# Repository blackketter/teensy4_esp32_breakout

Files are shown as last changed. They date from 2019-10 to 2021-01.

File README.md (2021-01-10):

A companion sidecar board with an ESP32 module to mate with the [Teensy 4 Header Breakout Board](https://github.com/blackketter/teensy4_header_breakout).  

It's designed to solder to the bottom 8 pins on the right side of the Teensy 4 Header Breakout. 

By default it can be powered by the 3.3v power supply on the Teensy, but this may be insufficient for WiFi transmission.  In that case, populate the power supply parts (C4, C5, U2), cut the 3.3v jumper and provide 5v to the indicated pin.

There's an LED on ESP32 pin IO22.

Designed in KiCad.

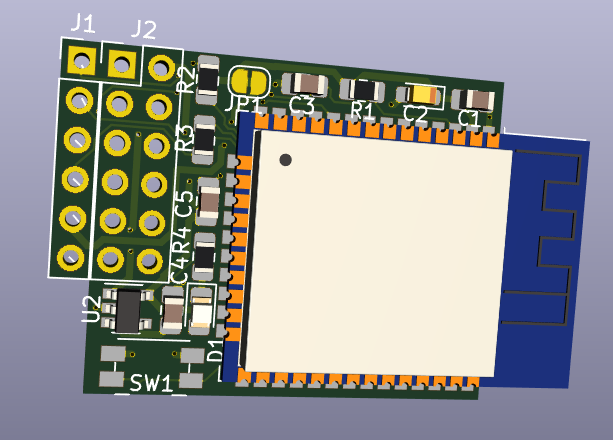
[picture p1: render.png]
breakout render

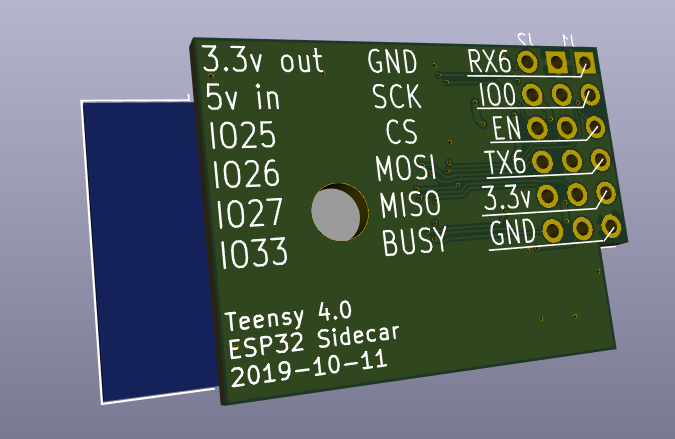
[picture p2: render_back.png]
breakout render back

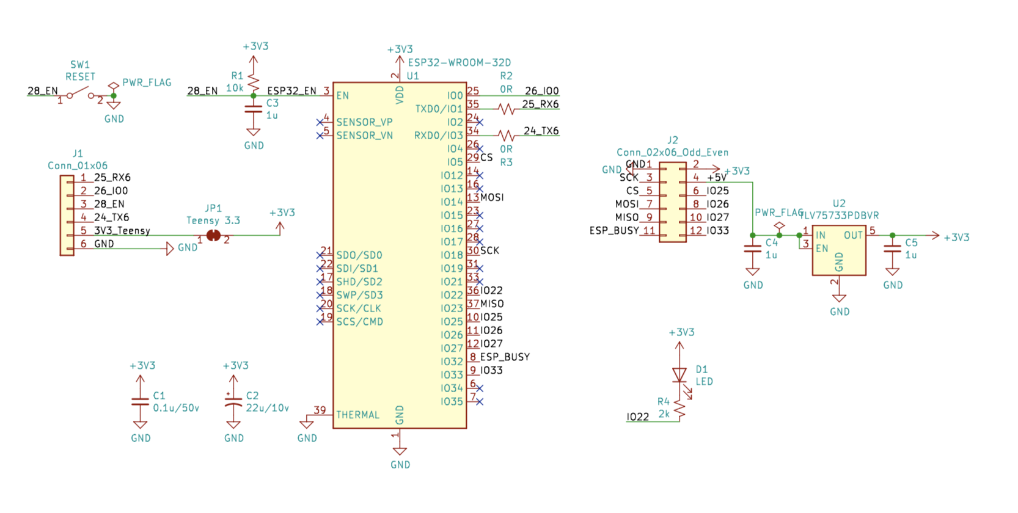
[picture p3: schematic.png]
schematic


Notes:

- In progress: First version worked, this version in progress.
- With longer header pins you should be able to flip the board to be under or over the Teensy 4.0
- Latest revision connects Teensy pin 28 to ESP32 EN

Pinout:

Column 1:

1. Teensy D25/RX6, ESP32 TX0/IO1
2. Teensy D26, ESP32 IO0
3. Teensy D28, ESP32 EN (Reset), On/Off
4. Teensy D24/TX6, ESP32 RX0/IO2
5. Teensy 3.3v
6. GND

Column 2:

1. GND
2. ESP32 IO18/SCK
3. ESP32 IO5/CS
4. ESP32 IO14/MOSI
5. ESP32 IO23/MISO
6. ESP32 IO32/ESP_BUSY

Column 3:

1. 3.3v Regulated Output (if using onboard regulator)
2. 5v Input To Regulator
3. ESP32 IO25, Green LED out
4. ESP32 IO26, Red LED out
5. ESP32 IO27, Blue LED out
6. ESP32 IO33

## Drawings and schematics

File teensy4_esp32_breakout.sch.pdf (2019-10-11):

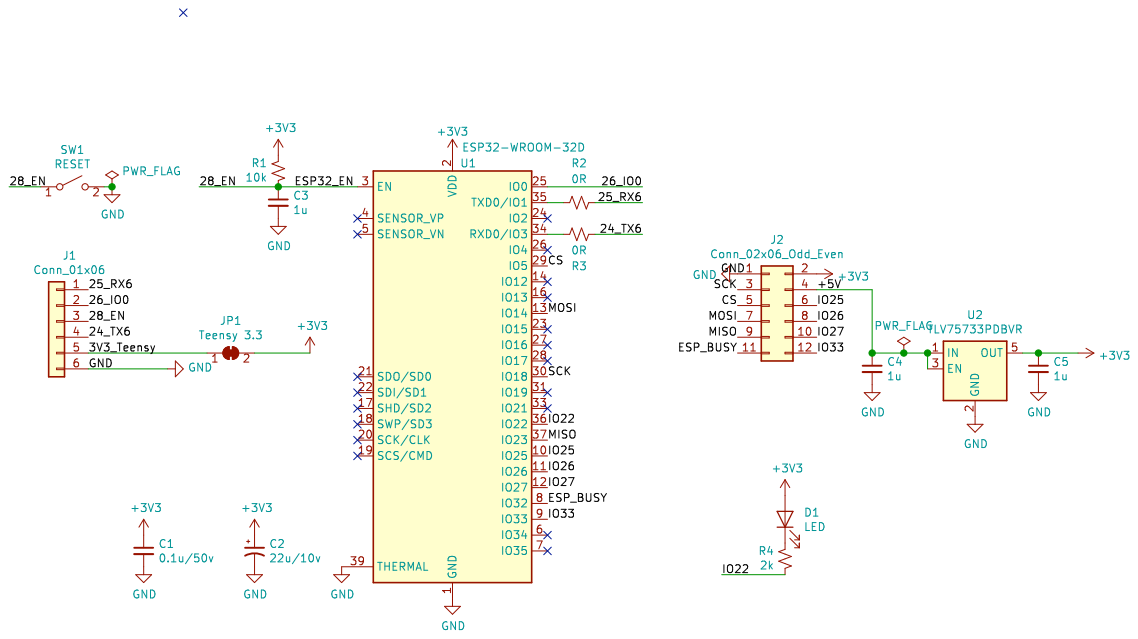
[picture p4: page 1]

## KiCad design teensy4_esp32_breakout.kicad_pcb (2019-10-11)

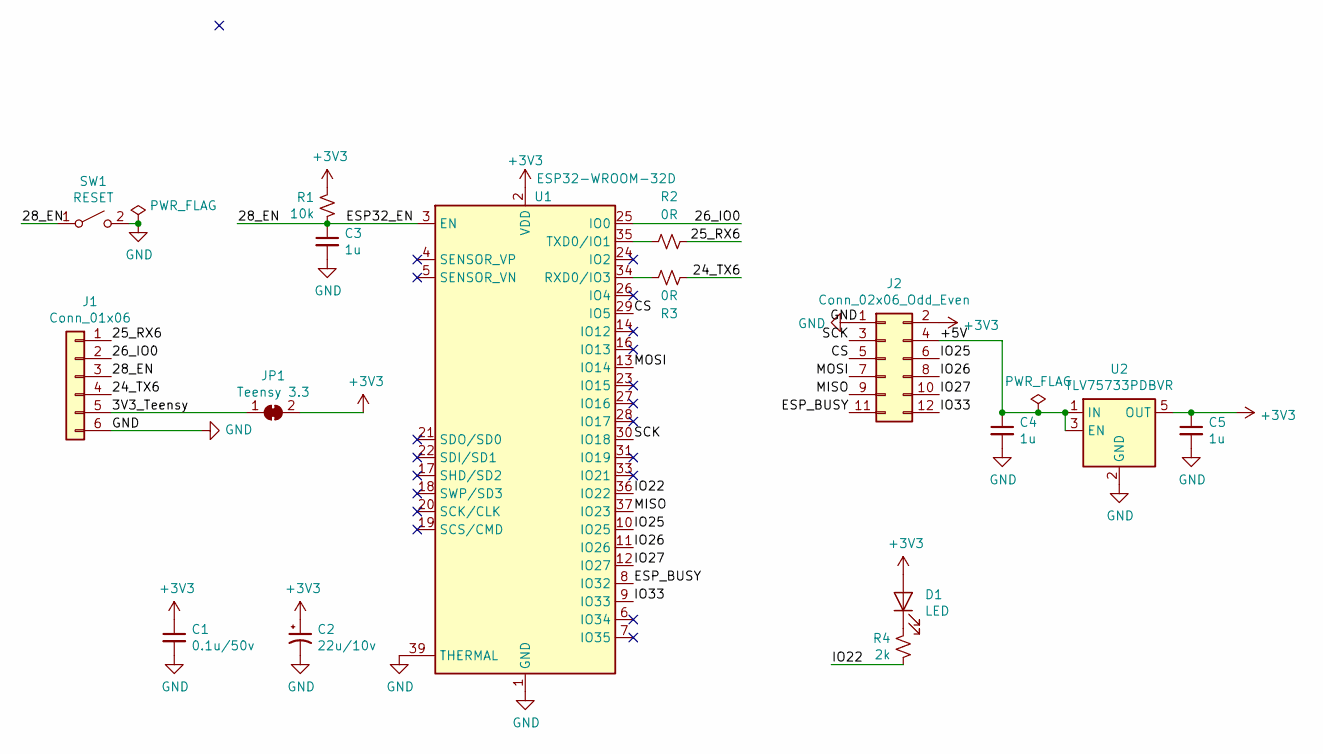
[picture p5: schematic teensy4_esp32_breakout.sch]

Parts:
C1: 0.1u/50v; C_0805_2012Metric_Pad1.15x1.40mm_HandSolder
C2: 22u/10v; CP_EIA-2012-12_Kemet-R_Pad1.30x1.05mm_HandSolder
C3, C4, C5: 1u; C_0805_2012Metric_Pad1.15x1.40mm_HandSolder
D1: LED; LED_0805_2012Metric_Pad1.15x1.40mm_HandSolder
J1: Conn_01x06; PinHeader_1x06_P2.54mm_Vertical
J2: Conn_02x06_Odd_Even; PinHeader_2x06_P2.54mm_Vertical
JP1: Teensy 3.3; SolderJumper-2_P1.3mm_Bridged_RoundedPad1.0x1.5mm
R1: 10k; R_0805_2012Metric_Pad1.15x1.40mm_HandSolder
R2, R3: 0R; R_0805_2012Metric_Pad1.15x1.40mm_HandSolder
R4: 2k; R_0805_2012Metric_Pad1.15x1.40mm_HandSolder
SW1: RESET; Panasonic_EVQPUJ_EVQPUA
U1: ESP32-WROOM-32D; ESP32-WROOM-32
U2: TLV75733PDBVR; SOT-23-5

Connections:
+3V3: C1.1, C2.1, C5.1, D1.2 (A), J2.2, JP1.2 (B), R1.2, U1.2 (VDD), U2.5 (OUT)
/3V3_Teensy: J1.5, JP1.1 (A)
/24_TX6: J1.4, R3.1
/25_RX6: J1.1, R2.1
/26_IO0: J1.2, U1.25 (IO0)
/28_EN: C3.1, J1.3, R1.1, SW1.1 (A), U1.3 (EN)
/+5V: C4.1, J2.4, U2.1 (IN), U2.3 (EN)
/CS: J2.5, U1.29 (IO5)
/ESP_BUSY: J2.11, U1.8 (IO32)
/IO22: R4.1, U1.36 (IO22)
/IO25: J2.6, U1.10 (IO25)
/IO26: J2.8, U1.11 (IO26)
/IO27: J2.10, U1.12 (IO27)
/IO33: J2.12, U1.9 (IO33)
/MISO: J2.9, U1.37 (IO23)
/MOSI: J2.7, U1.13 (IO14)
/SCK: J2.3, U1.30 (IO18)
GND: C1.2, C2.2, C3.2, C4.2, C5.2, J1.6, J2.1, SW1.2 (B), U1.1 (GND), U1.15 (GND), U1.38 (GND), U1.39 (THERMAL), U2.2 (GND)
unnamed: D1.1 (K), R4.2
unnamed: R2.2, U1.35 (TXD0/IO1)
unnamed: R3.2, U1.34 (RXD0/IO3)

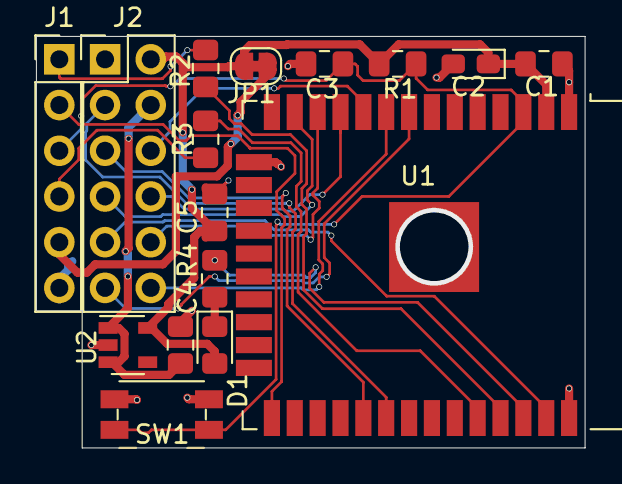
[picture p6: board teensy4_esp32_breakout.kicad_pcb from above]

Board: 2 copper layers, 30.5 x 22.9 mm, 16 parts (0 on the bottom side), 21 nets.

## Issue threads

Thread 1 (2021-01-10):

Change "Column 2:  ESP32 IO29/CS" to "Column 2:  ESP32 IO5/CS"

EsserPrototyping, 2021-01-10:
Hi!
I have seen that you have mixed up a Pin-Name / Pin-Number definition in your readme.md IO29/CS is ESP32 IO5/CS on the ESP32.

However - Nice project!
Is it working how you´ve intended? I´m making a Teensy 4.1 Test board myself and was wondering if the handling of the reset and enable pin is working fine, because on a lot ESP32 boards, there is not enought capacity on the enable pin in conjunction with the - often used - CP2104 serial IC, so the boot button is needed. But maybe this is nonsens if toggled by two pins of the Teensy directly.
I´m more experienced with ESP32 than Teensy..
Keep on! Steffen

Closed 2021-01-10.

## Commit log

2019-09-24 First draft
    [teensy4_esp32_breakout.kicad_pcb, teensy4_esp32_breakout.sch]
2019-09-24 Add draft bom
2019-09-24 Add PDF schematic
2019-09-24 Forgot to save
    [teensy4_esp32_breakout.kicad_pcb, teensy4_esp32_breakout.sch]
2019-09-25 Ordered this board with fix to remove double via and ground the BFV under ESP32
    [teensy4_esp32_breakout.kicad_pcb]
2019-09-25 fix regulator part number
    [teensy4_esp32_breakout.kicad_pcb, teensy4_esp32_breakout.sch]
2019-09-25 Added two more pins from ESP32 to header, including pin used for ESP_BUSY by WiFiNINA
    [teensy4_esp32_breakout.kicad_pcb, teensy4_esp32_breakout.sch]
2019-09-25 Fix missing wire, update silkscreen & readme
    [teensy4_esp32_breakout.kicad_pcb]
2019-10-11 Updates to remove program/on_off pin connections
    [teensy4_esp32_breakout.kicad_pcb, teensy4_esp32_breakout.sch]
2019-10-20 Added schematic
2021-01-10 Update README.md
    Fixed typo on ESP32 IO5/CS pin. Thanks @EsserPrototyping!
